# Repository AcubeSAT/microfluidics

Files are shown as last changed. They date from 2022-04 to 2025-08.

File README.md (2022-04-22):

## Description

A repository to host microfluidic chip design schematics and fabrication procedures.
The designs are heavily based on published ones from the [Laboratory of Biological Network Characterization](http://lbnc.epfl.ch/index.html) (LBNC) in EPFL. The LBNC designs can be found [here](http://lbnc.epfl.ch/microfluidic_designs.html). In this repository you will currently find `.dxf` AutoCAD files containing our modified design of the PDMS chip (located in `src/` folder), as well as various figures and `.drawio` files used in [AcubeSAT](https://acubesat.spacedot.gr/)'s [CDR](https://gitlab.com/acubesat/documentation/cdr-public/). You can find a prototype [flow layer](https://benchling.com/protocols/S5hXaszw/flow-layer-pdms-fabrication) and [control layer](https://benchling.com/protocols/ABdPP2IQ/control-layer-pdms-fabrication
) fabrication protocol over at Benchling.

---

<div align="center">
<p>
    <a href="https://benchling.com/organizations/acubesat/">Benchling 🎐🧬</a> &bull;
    <a href="https://gitlab.com/acubesat/documentation/cdr-public/-/blob/master/DDJF/DDJF_PL.pdf?expanded=true&viewer=rich">DDJF_PL 📚🧪</a> &bull;
    <a href="https://spacedot.gr/">SpaceDot 🌌🪐</a> &bull;
    <a href="https://acubesat.spacedot.gr/">AcubeSAT 🛰️🌎</a>
</p>
</div>

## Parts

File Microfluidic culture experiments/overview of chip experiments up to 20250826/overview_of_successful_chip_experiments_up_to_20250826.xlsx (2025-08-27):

Successful chip experiments sum up
 | date | sporulation sample used | total spotted chambers | spot-prime Δt | %viability (viable chambers/overall chambers) |  |  |  |  | chambers ID-FOV based (that grew) | confluency (%) of chambers presenting growth | sporulation medium suspension Δt (if any) | culture media used | Delta height-pressure between inlet-outlet (Δh between inlet and outlet syringes) | Refilling instances | Thermal control | Temperature plots-logs | imaging configuration used (inverted/non) | Chip in FOV by chamber ID | Bonding type | videos | Chip spot pattern | comments
 |  |  |  |  | overall % viability | R1 | R10 | R1-tr | R10-tr
1 | 202401103 | 20241015 (to be verified) since it could be this (https://benchling.com/acubesat/f/lib_Mjy77Noj-sporulations/etr_CO2dx6O2-sporulation-gb_nm-20241015/edit) | 82 | 30mins (+-10mins) | 57.14 | 40% (14/35) | 55.3% (26/47) | N/A | N/A | R1: 1.1 | 2.1 | 4.1 | 1.2 | 2.2 | 3.2 | 5.2 | 4.4 | 5.1 |5.2 | 5.4 | 5.5| 6.1 | 7.1 |||| R10: 1.8 | 1.9 | 1.12 | 2.11 | 2.8 | 2.12 | 3.9 | 3.8 | 3.11 | 3.12 | 4.8 | 4.9 | 4.11 | 4.12 | 5.8 | 5.9 | 5.12 |6.8 | 6.9 | 6.11 | 6.12 | 7.8 | 7.9 | 7.11 | 7.12 ||| 3.15 | 3.18 | 4.18 | - | N/A | YPD | 5cm | refill-flushin after 25h_45 and 40h_45 with syringe | incubator | N/A | inverted chip using this slide holder. Amazon microscope used (https://gitlab.com/acubesat/su/microfluidics/-/blob/master/microfluidic%20setup%20cads/slide_holder_13mm_height__+1mm__-invetred_priming.SLDPRT) | Rows 1-7 Columns 1-18+ | plasma pen | https://gitlab.com/acubesat/su/microfluidics/-/issues/42#note_2191269109 | https://gitlab.com/acubesat/su/microfluidics/-/issues/42#note_2191269109 | high viability can be disputed since the imaging doesn't allow for detection of cross contamination (It is however noteworthy that all visible cross contaminations were not measured as viable chambers)
2 | 20241230-20250101 | 20241015 (https://benchling.com/acubesat/f/lib_Mjy77Noj-sporulations/etr_CO2dx6O2-sporulation-gb_nm-20241015/edit) | 30 | 15-30mins | 26.6 % | N/A | N/A | 26.6% (8/30) | N/A | 1.1 | 87.21325927 | 12h | YPD+G418 | 3cm, inlet and outlet syringe horizontal (syringe retention used) | no refilling instances: the syringe retention mechanism was used to sustain flow (approximately 360deg of rotation after engagement) | amscope illumination stage (incandescent lamp), 22-25deg C ambient temp. Verified 30degC of incubation with the thermal camera | N/A | Amscope illumination stage and Andonstar microscpoe | Rows 1-8 Columns 1-11 | plasma pen | https://gitlab.com/acubesat/su/microfluidics/-/issues/42#note_2370847060 | https://gitlab.com/acubesat/su/microfluidics/-/blob/master/Microfluidic%20culture%20experiments/NM_20241230-20250101_lab2/NM_20241230-20250101_lab2_spotting_l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 | -
 |  |  |  |  |  |  |  |  |  | 1.2 | 82.60456288
 |  |  |  |  |  |  |  |  |  | 3.1 | 75.69255852
 |  |  |  |  |  |  |  |  |  | 5.1 | 80.44540996
 |  |  |  |  |  |  |  |  |  | 5.8 | 80.30826916
 |  |  |  |  |  |  |  |  |  | 6.1 | 68.57686099
 |  |  |  |  |  |  |  |  |  | 6.2 | 72.55567655
 |  |  |  |  |  |  |  |  |  | 6.5 | 52.5258008
3 | 20250715-0724-0728 | 20241015 (allocates of each strain were converted to 10% trehalose specimens on 202504) (https://benchling.com/acubesat/f/lib_Mjy77Noj-sporulations/etr_CO2dx6O2-sporulation-gb_nm-20241015/edit) | 88 (but 10 in the initial FOV) | 30mins | unknown due to unfortunate FOV (and cross contamination that followed) | - | - | - | - | ? | ? | N/A | YPD+G418 | microscope setup: 40cm, horizontal orientation of syringes. |||. stereoscope setup: 14cm, inlet syringe in vertical orientation, outlet in horizontal (syringe retention used: each refilling means 360deg of rotation after engagement) | 20250717 refilling at about 10:15 ||| 20250718 refilling at about 11:15 ||| 20250722 refilling at 15.18-20 ||| delam on mispotted chamber 20250724 refilling at about 1.20 ||| vid in obs 20250728 refilling at 12:28 vid in phone |||. at about 13:33 change outlet-inlet side due to reservoir. |||. 20250731 15:05 refilling | Geomatec heater connected to 5V in arduino Uno R3. Verified incubation temp at 30deg with aht20 sensor. Tested uniformity and temp to be 33deg C with the thermal camera (while connected to the 5v arduino line). The aht20 sensor was mounted to the heater using scotch tape until 0724 11:27. It was later secured with excess kapton on the heater until the end of the test (inside the stereoscope). Note:The stereoscope and the microscope used were constantly covered with their plastic covers | https://gitlab.com/acubesat/su/microfluidics/-/blob/master/Microfluidic%20culture%20experiments/20250715-0724-0728/Temperature_logs-plot_20250715-0731.html | Zeis Axioscop 40 until 0721 14:00 ||| Leica stereoscope with ximea camera inside an eyepiece until 0724 12:30. |||.after 0724 12:38 Leicas native camera was used (required w7 computer) | Rows 1-2 Columns 22-26 | plasma pen | The timelapse video is linked here, it includes all frames in a 15fps video with displayed timestamp and time elapsed from priming. In this displayed elapsed time 21 minutes should be added since priming occured at 0715 14:16 (https://cloud.spacedot.gr/index.php/apps/files/files/594743?openfile=true) | https://gitlab.com/acubesat/su/microfluidics/-/blob/master/Microfluidic%20culture%20experiments/20250715-0724-0728/NM_20250715_CERTH__spotting___logs_-_Sheet1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 | -
4 | 20250723-0801 | 20241015 (allocates of each strain were converted to 10% trehalose specimens on 202504) (https://benchling.com/acubesat/f/lib_Mjy77Noj-sporulations/etr_CO2dx6O2-sporulation-gb_nm-20241015/edit) | 130 (but 59 in FOV) | 30mins | 10.16% | N/A | N/A | 11.36% (5/44) | 6.66% (1/15) | 2,6 (R1-tr) | 8.62700393 | N/A | YPD+G418 | 7cm, inlet syringe in vertical orientation, outlet in horizontal | pump: 0723 4:05, settings: p50-s3-at3mins_p3-s3. |||. 0729 00:00 ||| 0730 7:30 syringe refill ||| 0730 11:50 syringe refill | Incubator. worked until 0728 approximately 20:00. Sensor readings available are ambient temperature. Due to a logging issue in a script most temps were not logged (an arduino nano-esp32 was used instead of the previously tested UNO. After necessary compatibility changes on the .ino script and the python logger-script the sensor appeared to be saving the values but the output csv files were in fact empty, smth which I later realised). Scrolling through the data on the terminal no ambient temp of more than 34deg C was observed. 0728 18:53 incubator temp was observed to be 17.1deg C and the aht20 sensor listed an ambient temp of 33.8deg C | ambient: https://gitlab.com/acubesat/su/microfluidics/-/blob/master/Microfluidic%20culture%20experiments/NM_20250723-0801_lab2/Temp%20&%20RH%20plots-data/aht20_timelin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 | The andonstar microscope was used with the chip inverted inside the slide holder. A custom illumination setup was used including a LED strip attached into the internal walls of the holder. (the andonstar rack and lighting wouldn't fit inside the incubator). To fit the andonstar inside the incubator the andonstar camera-lense was mounted onto the rack of the cainda-amazon- microscope in an intricate and "fragile" setup (not easy to setup and change FOV) (https://gitlab.com/acubesat/su/microfluidics/-/blob/master/microfluidic%20setup%20cads/slide_holder_13mm_height__+1mm__-invetred_priming.SLDPRT) | Rows 1-5 Columns 1-22 | microwave plasma treatement: Initial plasma treatment was unsuccessful (no plasma sparked near the chip) during which the chip was exposed to microwaves for 7seconds (video log available). The vacuum jar was reevacuated and placed again inside the microwave oven for 6 seconds. This time plasma sparked on the chip and slide. Bonding was subsequently immediate and strong | The timelapse video is linked here, it includes all frames in a 15fps video with displayed timestamp and time elapsed from priming. Priming of the chip occured at 07:23 1:48 so real elapsed time should be calculated based on this (there seems to be a problem in the initially shown elapsed time). Regarding the elapsed time shown after 0723 20:00 19h 28minutes and 50seconds need to be added to reflect the correct elapsed time (https://cloud.spacedot.gr/index.php/apps/files/files/594858?openfile=true) | https://gitlab.com/acubesat/su/microfluidics/-/blob/master/Microfluidic%20culture%20experiments/NM_20250723-0801_lab2/NM_20250723_lab2_spotting_layout__logs__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 | This is the first successful microfluidic culture with microwave plasma bonded chip! This validates the method for future testing. The spores endured 13s exposure to microwaves which is impressive (it is quite likely the reason for the significant decrease in viability)
 |  |  |  |  |  |  |  |  |  | 2,7 (R1-tr) | 100.7921616
 |  |  |  |  |  |  |  |  |  | 2,15 (R1-tr) | 29.61937955
 |  |  |  |  |  |  |  |  |  | 1,8 (R1-tr) | 8.483221005
 |  |  |  |  |  |  |  |  |  | 1,15 (R1-tr) | 50.97121498
 |  |  |  |  |  |  |  |  |  | 3.22 (R10-tr) | 35.9865942

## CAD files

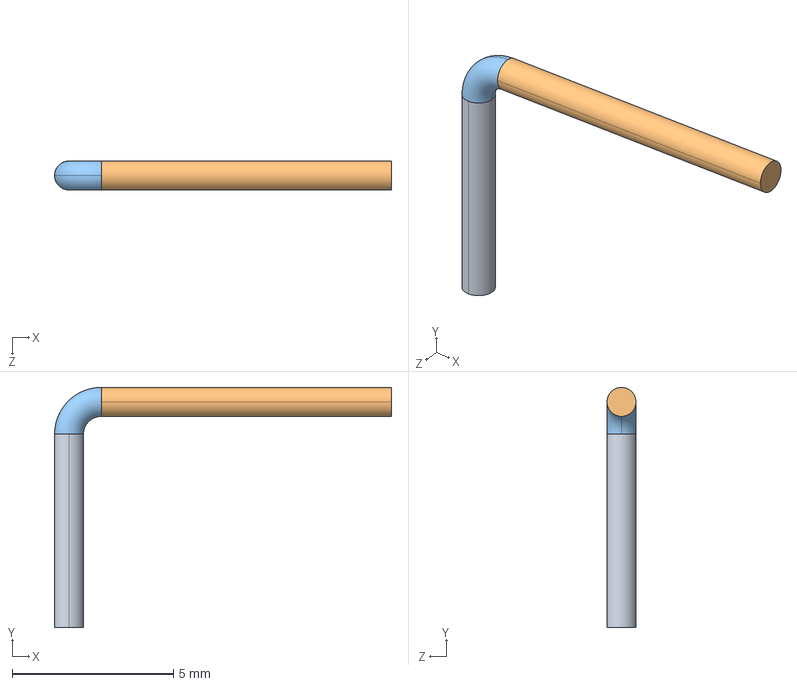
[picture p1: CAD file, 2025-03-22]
microfluidic setup cads/Pin cads/0.9mm 20G solid pin/corrected_0.9mmOD_20G_solid_pin.STEP
10.5 x 7.45 x 0.9 mm

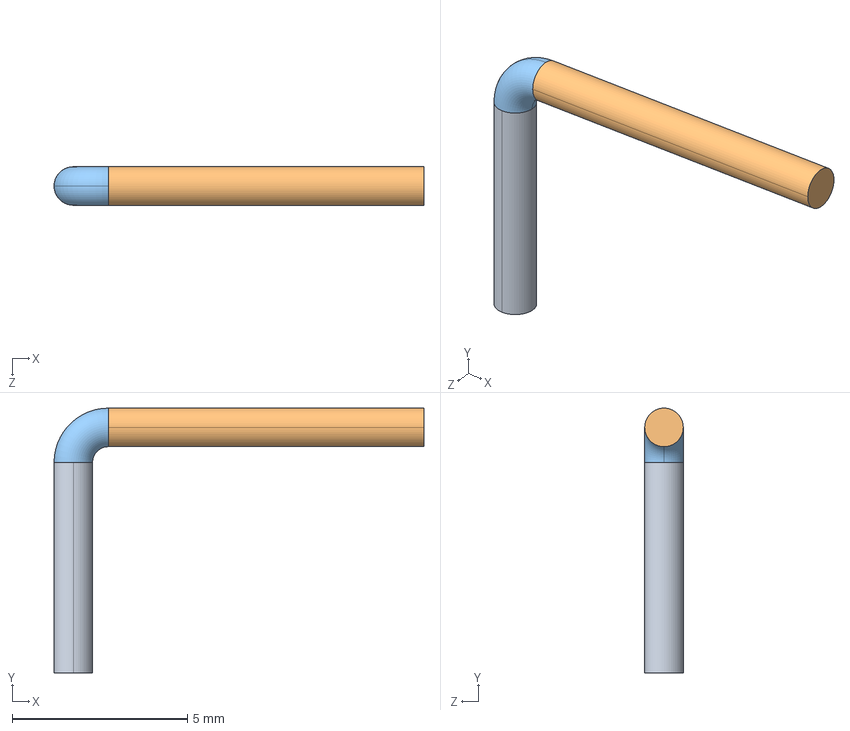
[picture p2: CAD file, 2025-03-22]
microfluidic setup cads/Pin cads/1.1mm solid pin/1.1_mmOD_solid_pin.STEP
10.6 x 7.55 x 1.10 mm

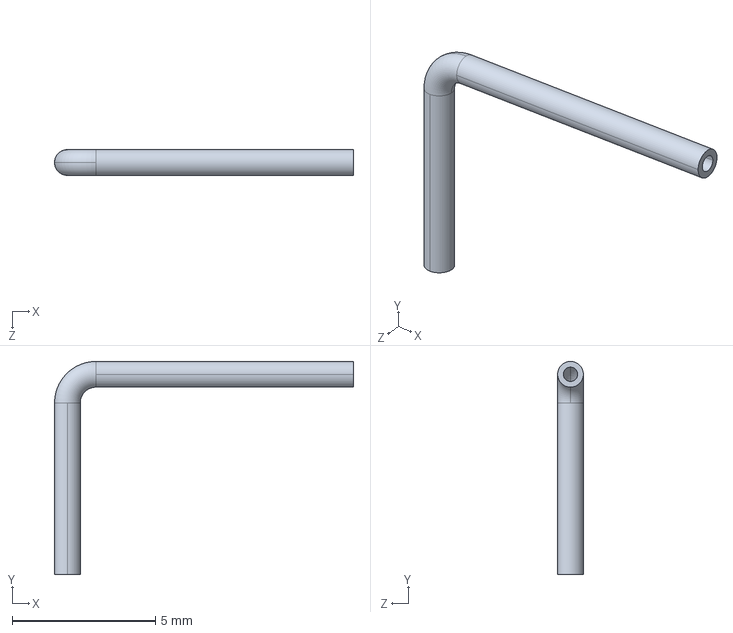
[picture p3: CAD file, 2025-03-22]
microfluidic setup cads/Pin cads/20G hollow pins -0.9mmOD 0.5mmID/20G_pins_-hollow-_0.5mmID_and_0.9mm_OD.STEP
10.5 x 7.45 x 0.9 mm

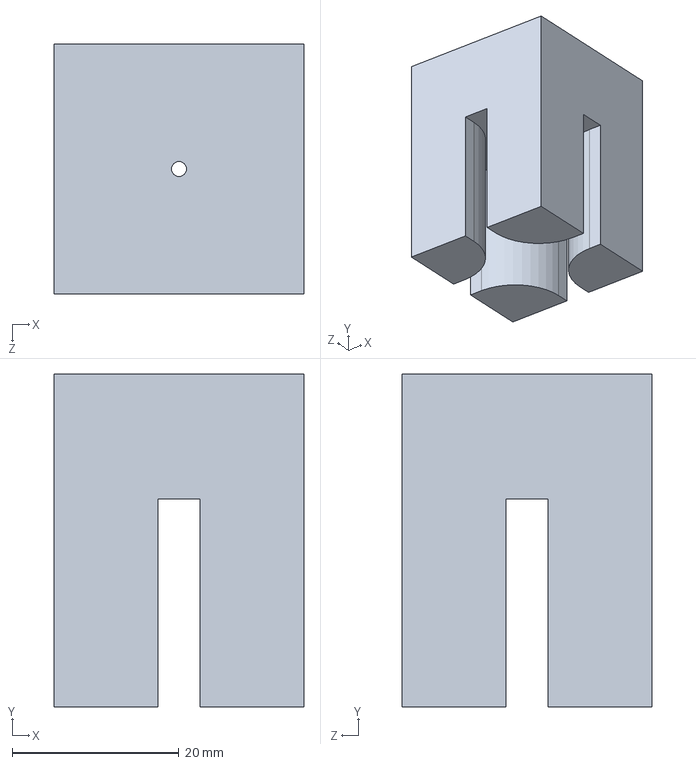
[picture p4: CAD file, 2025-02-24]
microfluidic setup cads/pin_holder_sonicator.SLDPRT
30.0 x 40.0 x 30.0 mm

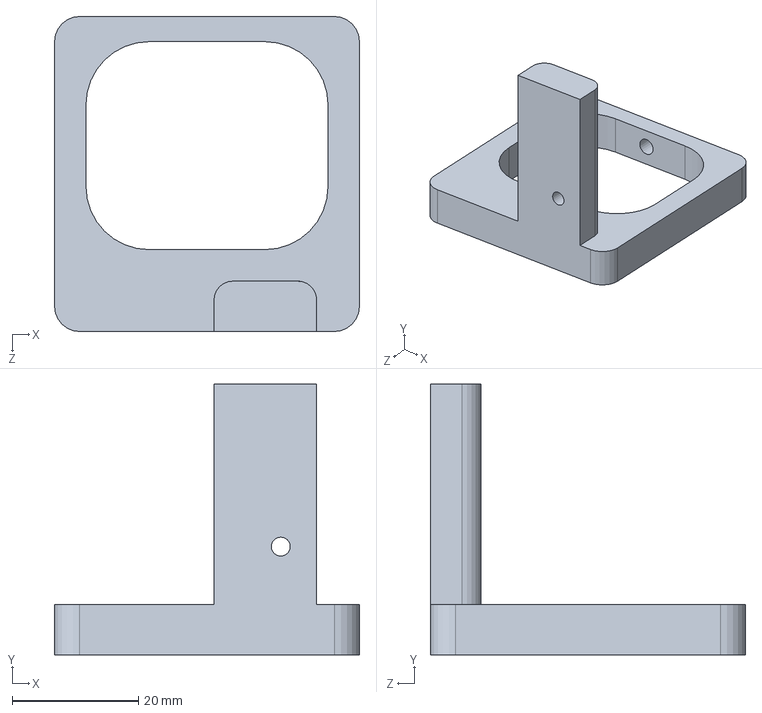
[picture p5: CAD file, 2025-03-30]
microfluidic setup cads/Spotter-bonding-cads/spotter-bond-V4/pen_holder_part_v2.SLDPRT
48.4 x 43.0 x 50.0 mm

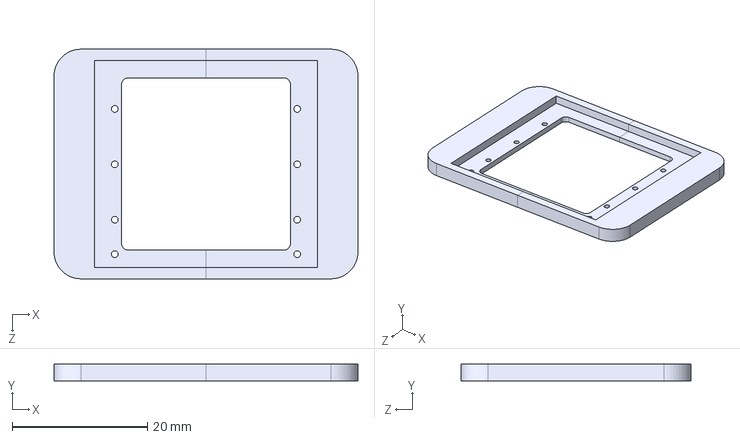
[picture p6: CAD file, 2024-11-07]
microfluidic setup cads/Spacer-Sheet_cad_1mm_-cut.STEP
45.0 x 2.50 x 34.0 mm

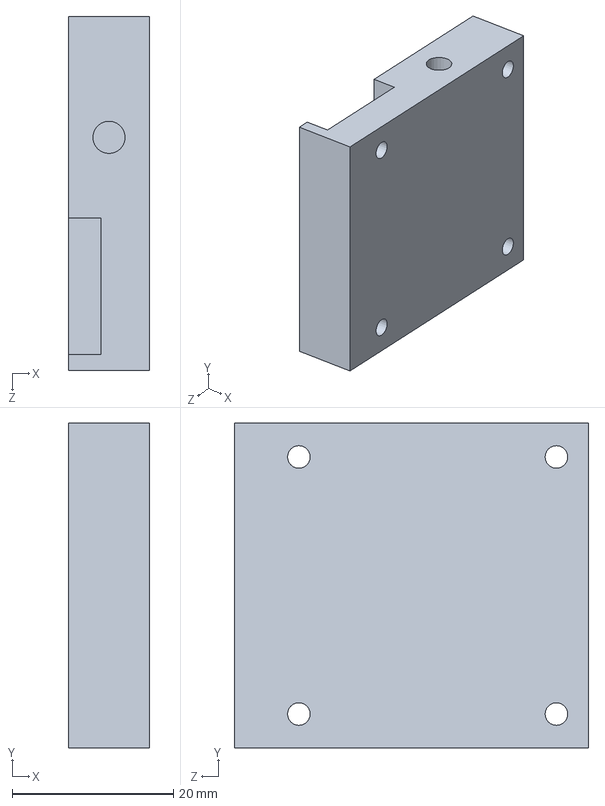
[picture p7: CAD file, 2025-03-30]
microfluidic setup cads/Spotter-bonding-cads/spotter-bond-V4/pin_holder_2_for_pen_upside.SLDPRT
10.0 x 40.3 x 43.9 mm

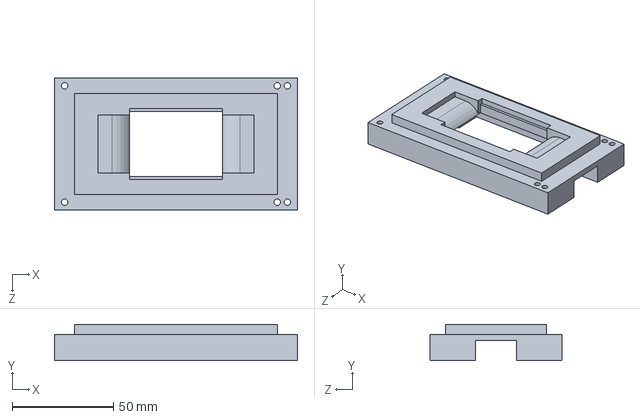
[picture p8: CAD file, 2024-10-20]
microfluidic setup cads/slide_holder_13mm_height__+1mm__-invetred_priming.SLDPRT
120.0 x 18.0 x 65.0 mm

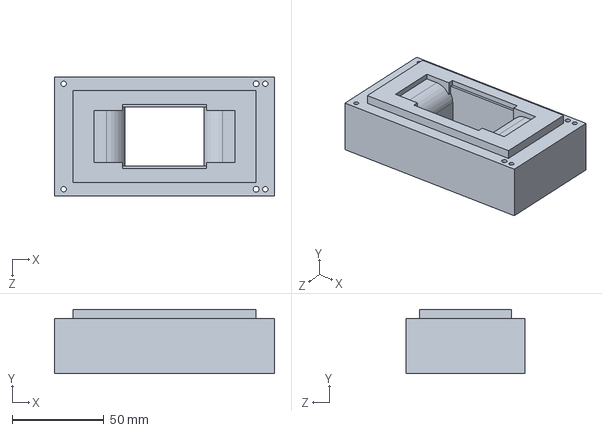
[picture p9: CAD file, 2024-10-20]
microfluidic setup cads/slide_holder__v1_-31mm_height.SLDPRT
120.0 x 35.0 x 65.0 mm

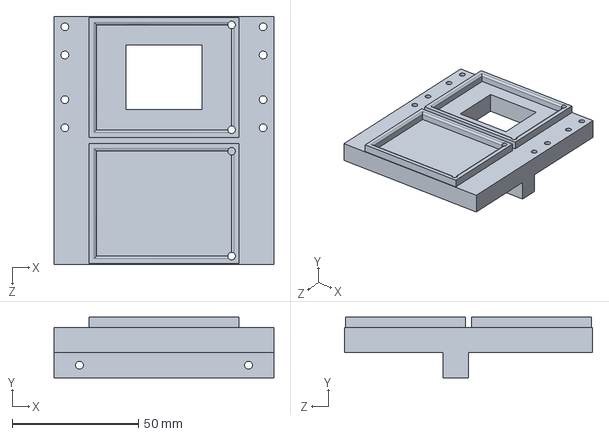
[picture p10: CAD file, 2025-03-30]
microfluidic setup cads/Spotter-bonding-cads/spotter-bond-V4/double_holder_slot__for_top_and_bottom_v4.SLDPRT
86.9 x 24.0 x 98.2 mm

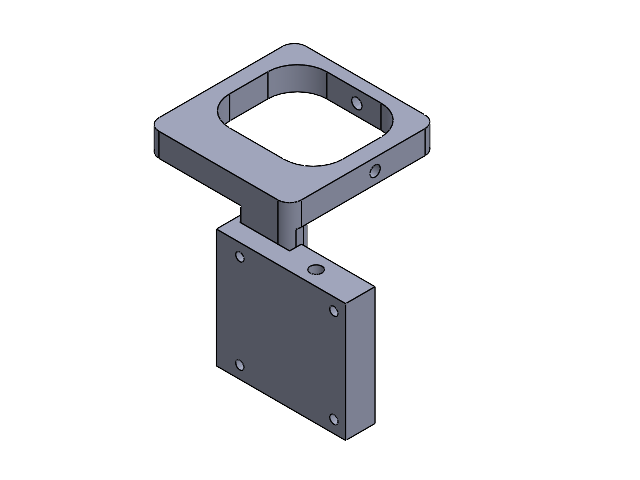
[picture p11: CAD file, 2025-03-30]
microfluidic setup cads/Spotter-bonding-cads/spotter-bond-V4/assembly_v2_pen_holder.SLDASM
pin holder 2 for pen upside
Part2^chip hold align pin insert

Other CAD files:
src/baseline/MITOMI_spacedot_complete.dxf
src/designs/Biodisplay_spacedot_CDR_complete.dxf
original/biodisplay.dxf
src/designs/MITOMI_incr_dist_spacedot.dxf
src/baseline/MITOMI_spacedot.dxf
src/designs/Biodisplay_spacedot.dxf
src/designs/Biodisplay_spacedot_CDR_sub.dxf
microfluidic setup cads/Pin cads/0.9mm 20G solid pin/corrected_0.9mmOD_20G_solid_pin.SLDPRT
microfluidic setup cads/Pin cads/0.9mm 20G solid pin/corrected_0.9mmOD_20G_solid_pin.STL
microfluidic setup cads/Pin cads/1.1mm solid pin/1.1_mmOD_solid_pin.SLDPRT
microfluidic setup cads/Pin cads/1.1mm solid pin/1.1_mmOD_solid_pin.STL
microfluidic setup cads/Pin cads/20G hollow pins -0.9mmOD 0.5mmID/20G_pins_-hollow-_0.5mmID_and_0.9mm_OD.SLDPRT
microfluidic setup cads/Pin cads/20G hollow pins -0.9mmOD 0.5mmID/20G_pins_-hollow-_0.5mmID_and_0.9mm_OD.STL
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

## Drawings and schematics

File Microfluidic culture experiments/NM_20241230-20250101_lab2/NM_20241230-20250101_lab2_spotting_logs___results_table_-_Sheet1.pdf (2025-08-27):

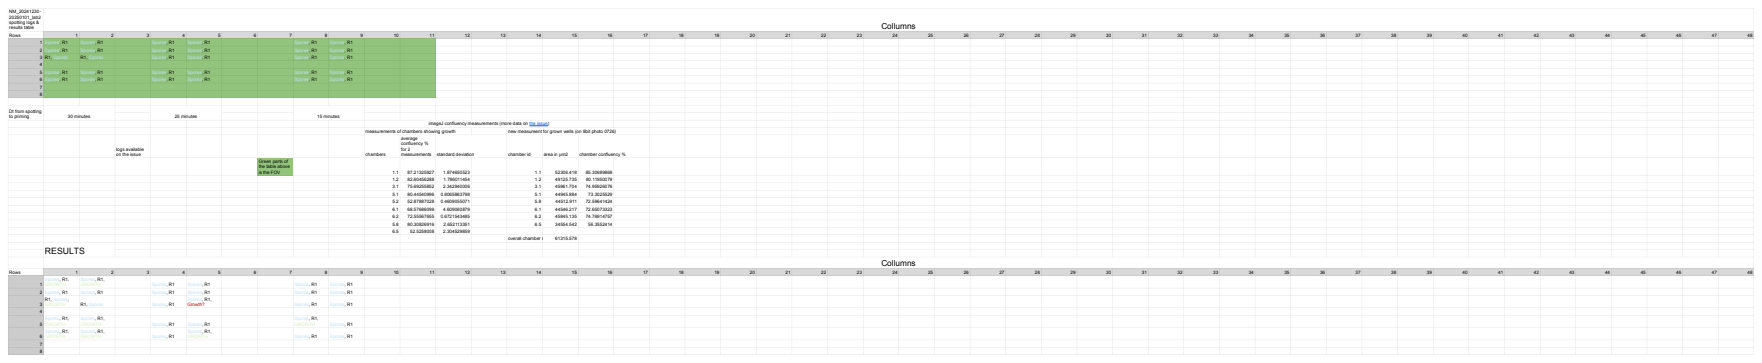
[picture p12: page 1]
NM_20241230- 20250101_lab2 spotting logs & results table; Collumns; Rows; Spores, R1; Spores, R1 2; Spores, R1 3; R1, Spores; Spores, R1 45; Spores, R1 6; Spores, R1 78 Dt from spotting; to priming; 30 minutes; 25 minutes; 15 minutes; imageJ confluency measurements (more data on the issue) measurements of chambers showing growth; new measureent for grown wells (on 8bit photo 0726); logs available on the issue; chambers; average confluency %; for 2 measurements; standard deviation; chamber id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

Green parts of
the table above

Rows | Spores, R1, GROWTH 1 2 3 4 5 6 7 8 9 10 11 12 13 14 15 16 17 18 19 20 21 22 23 24 25 26 27 28 29 30 31 32 33 34 35 36 37 38 39 40 41 42 43 44 45 46 47 48 1

Spores, R1 R1, Spores, GROWTH Spores, R1, GROWTH Spores, R1, GROWTH Spores, R1 R1, Spores Spores, R1 Spores, R1 Spores, R1 Spores, R1 Spores, R1 Spores, R1, Growth? Spores, R1 Spores, R1 Spores, R1 Spores, R1 2 Spores, R1 3 Spores, R1 45 Spores, R1, GROWTH Spores, R1, GROWTH Spores, R1 Spores, R1 Spores, R1, GROWTH Spores, R1 6 Spores, R1, GROWTH Spores, R1 Spores, R1, GROWTH Spores, R1 Spores, R1 78

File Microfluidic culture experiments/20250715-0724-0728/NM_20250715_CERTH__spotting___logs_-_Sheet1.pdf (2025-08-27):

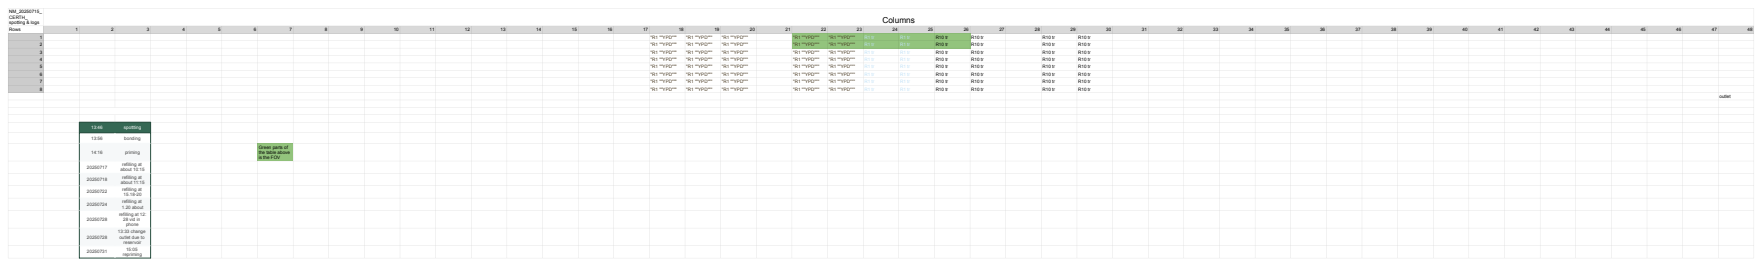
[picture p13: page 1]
NM_20250715_ CERTH_ spotting & logs; Columns; Rows; "R1 ""YPD"""; outlet; priming; Green parts of

13:46 | spottting

13:56 | bonding

20250717 | refilling at about 10:15

the table above
is the FOV

20250718 | refilling at about 11:15

20250722 | refilling at 15.18-20

20250724 | refilling at 1.20 about 20250728

refilling at 12: 28 vid in phone

20250728 | 13:33 change outlet due to reservoir 20250731 15:05 repriming

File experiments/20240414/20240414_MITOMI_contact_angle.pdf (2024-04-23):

Left | Middle | Right

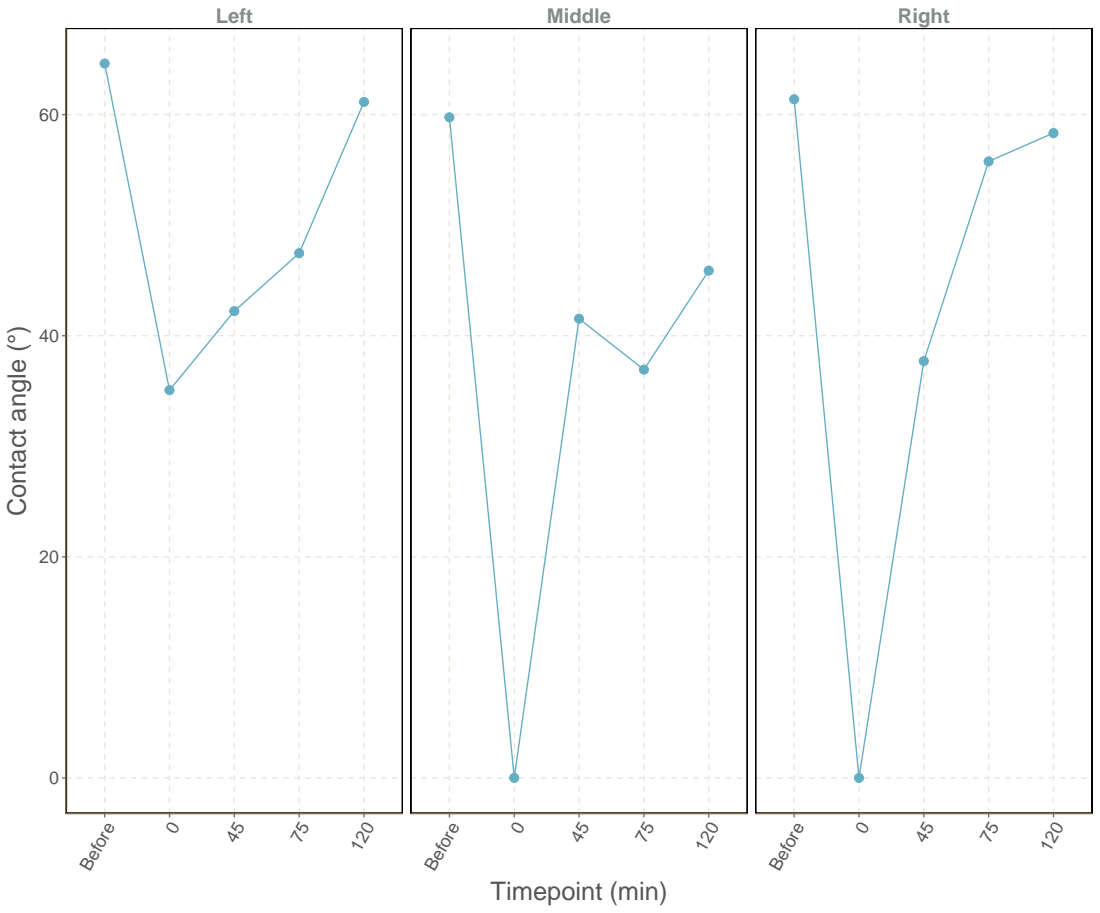
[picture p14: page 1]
Before; Timepoint (min); Contact angle (°)

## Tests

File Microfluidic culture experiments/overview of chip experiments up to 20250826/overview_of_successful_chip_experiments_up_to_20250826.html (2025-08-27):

| A | B | C | D | E | F | G | H | I | J | K | L | M | N | O | P | Q | R | S | T | U | V | W | X | Y | Z | AA
1
2 | | | Successful chip experiments sum up
3 | | | | date | sporulation sample used | total spotted chambers | spot-prime Δt | %viability (viable chambers/overall chambers) | | | | | chambers ID-FOV based (that grew) | confluency (%) of chambers presenting growth | sporulation medium suspension Δt (if any) | culture media used | Delta height-pressure between inlet-outlet (Δh between inlet and outlet syringes) | Refilling instances | Thermal control | Temperature plots-logs | imaging configuration used (inverted/non) | Chip in FOV by chamber ID | Bonding type | videos | Chip spot pattern | comments
4 | | | | | | | | overall % viability | R1 | R10 | R1-tr | R10-tr
5 | | | 1 | 202401103 | 20241015 (to be verified) (https://benchling.com/acubesat/f/lib_Mjy77Noj-sporulations/etr_CO2dx6O2-sporulation-gb_nm-20241015/edit) since it could be this (https://benchling.com/acubesat/f/lib_Mjy77Noj-sporulations/etr_Rs7Qbz9h-sporulation-nm-20240920/edit) | 82 | 30mins (+-10mins) | 57.14 | 40% (14/35) | 55.3% (26/47) | N/A | N/A | R1: 1.1 | 2.1 | 4.1 | 1.2 | 2.2 | 3.2 | 5.2 | 4.4 | 5.1 |5.2 | 5.4 | 5.5| 6.1 | 7.1 |||| R10: 1.8 | 1.9 | 1.12 | 2.11 | 2.8 | 2.12 | 3.9 | 3.8 | 3.11 | 3.12 | 4.8 | 4.9 | 4.11 | 4.12 | 5.8 | 5.9 | 5.12 |6.8 | 6.9 | 6.11 | 6.12 | 7.8 | 7.9 | 7.11 | 7.12 ||| 3.15 | 3.18 | 4.18 | - | N/A | YPD | 5cm | refill-flushin after 25h_45 and 40h_45 with syringe | incubator | N/A | inverted chip using this (https://gitlab.com/acubesat/su/microfluidics/-/blob/master/microfluidic%20setup%20cads/slide_holder_13mm_height__+1mm__-invetred_priming.SLDPRT) slide holder. Amazon microscope used | Rows 1-7 Columns 1-18+ | plasma pen | https://gitlab.com/acubesat/su/microfluidics/-/issues/42#note_2191269109 | https://gitlab.com/acubesat/su/microfluidics/-/issues/42#note_2191269109 | high viability can be disputed since the imaging doesn't allow for detection of cross contamination (It is however noteworthy that all visible cross contaminations were not measured as viable chambers)
6 | | | 2 | 20241230-20250101 | 20241015 (https://benchling.com/acubesat/f/lib_Mjy77Noj-sporulations/etr_CO2dx6O2-sporulation-gb_nm-20241015/edit) | 30 | 15-30mins | 26.6 % | N/A | N/A | 26.6% (8/30) | N/A | 1.1 | 87.21325927 | 12h | YPD+G418 | 3cm, inlet and outlet syringe horizontal (syringe retention used) | no refilling instances: the syringe retention mechanism was used to sustain flow (approximately 360deg of rotation after engagement) | amscope illumination stage (incandescent lamp), 22-25deg C ambient temp. Verified 30degC of incubation with the thermal camera | N/A | Amscope illumination stage and Andonstar microscpoe | Rows 1-8 Columns 1-11 | plasma pen | https://gitlab.com/acubesat/su/microfluidics/-/issues/42#note_2370847060 | https://gitlab.com/acubesat/su/microfluidics/-/blob/master/Microfluidic%20culture%20experiments/NM_20241230-20250101_lab2/NM_20241230-20250101_lab2_spotting_logs___r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 | -
7 | | | | | | | | | | | | | 1.2 | 82.60456288
8 | | | | | | | | | | | | | 3.1 | 75.69255852
9 | | | | | | | | | | | | | 5.1 | 80.44540996
10 | | | | | | | | | | | | | 5.8 | 80.30826916
11 | | | | | | | | | | | | | 6.1 | 68.57686099
12 | | | | | | | | | | | | | 6.2 | 72.55567655
13 | | | | | | | | | | | | | 6.5 | 52.5258008
14 | | | 3 | 20250715-0724-0728 | 20241015 (https://benchling.com/acubesat/f/lib_Mjy77Noj-sporulations/etr_CO2dx6O2-sporulation-gb_nm-20241015/edit) (allocates of each strain were converted to 10% trehalose specimens on 202504) | 88 (but 10 in the initial FOV) | 30mins | unknown due to unfortunate FOV (and cross contamination that followed) | - | - | - | - | ? | ? | N/A | YPD+G418 | microscope setup: 40cm, horizontal orientation of syringes. |||. stereoscope setup: 14cm, inlet syringe in vertical orientation, outlet in horizontal (syringe retention used: each refilling means 360deg of rotation after engagement) | 20250717 refilling at about 10:15 ||| 20250718 refilling at about 11:15 ||| 20250722 refilling at 15.18-20 ||| delam on mispotted chamber 20250724 refilling at about 1.20 ||| vid in obs 20250728 refilling at 12:28 vid in phone |||. at about 13:33 change outlet-inlet side due to reservoir. |||. 20250731 15:05 refilling | Geomatec heater connected to 5V in arduino Uno R3. Verified incubation temp at 30deg with aht20 sensor. Tested uniformity and temp to be 33deg C with the thermal camera (while connected to the 5v arduino line). The aht20 sensor was mounted to the heater using scotch tape until 0724 11:27. It was later secured with excess kapton on the heater until the end of the test (inside the stereoscope). Note:The stereoscope and the microscope used were constantly covered with their plastic covers | https://gitlab.com/acubesat/su/microfluidics/-/blob/master/Microfluidic%20culture%20experiments/20250715-0724-0728/Temperature_logs-plot_20250715-0731.html | Zeis Axioscop 40 until 0721 14:00 ||| Leica stereoscope with ximea camera inside an eyepiece until 0724 12:30. |||.after 0724 12:38 Leicas native camera was used (required w7 computer) | Rows 1-2 Columns 22-26 | plasma pen | The timelapse video is linked here (https://cloud.spacedot.gr/index.php/apps/files/files/594743?openfile=true), it includes all frames in a 15fps video with displayed timestamp and time elapsed from priming. In this displayed elapsed time 21 minutes should be added since priming occured at 0715 14:16 | https://gitlab.com/acubesat/su/microfluidics/-/blob/master/Microfluidic%20culture%20experiments/20250715-0724-0728/NM_20250715_CERTH__spotting___logs_-_Sheet1.pdf | -

15

4

20250723-0801

20241015 (https://benchling.com/acubesat/f/lib_Mjy77Noj-sporulations/etr_CO2dx6O2-sporulation-gb_nm-20241015/edit) (allocates of each strain were converted to 10% trehalose specimens on 202504)

130 (but 59 in FOV)

30mins

10.16%

N/A

N/A

11.36% (5/44)

6.66% (1/15)

2,6 (R1-tr)

8.62700393

N/A

YPD+G418

7cm, inlet syringe in vertical orientation, outlet in horizontal

pump: 0723 4:05, settings: p50-s3-at3mins_p3-s3. |||. 0729 00:00 ||| 0730 7:30 syringe refill ||| 0730 11:50 syringe refill

Incubator. worked until 0728 approximately 20:00. Sensor readings available are ambient temperature. Due to a logging issue in a script most temps were not logged (an arduino nano-esp32 was used instead of the previously tested UNO. After necessary compatibility changes on the .ino script and the python logger-script the sensor appeared to be saving the values but the output csv files were in fact empty, smth which I later realised). Scrolling through the data on the terminal no ambient temp of more than 34deg C was observed. 0728 18:53 incubator temp was observed to be 17.1deg C and the aht20 sensor listed an ambient temp of 33.8deg C

ambient: https://gitlab.com/acubesat/su/microfluidics/-/blob/master/Microfluidic%20culture%20experiments/NM_20250723-0801_lab2/Temp%20&%20RH%20plots-data/aht20_timeline_20250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

The andonstar microscope was used with the chip inverted inside the slide holder (https://gitlab.com/acubesat/su/microfluidics/-/blob/master/microfluidic%20setup%20cads/slide_holder_13mm_height__+1mm__-invetred_priming.SLDPRT). A custom illumination setup was used including a LED strip attached into the internal walls of the holder. (the andonstar rack and lighting wouldn't fit inside the incubator). To fit the andonstar inside the incubator the andonstar camera-lense was mounted onto the rack of the cainda-amazon- microscope (https://www.amazon.de/dp/B081L4Y98G?psc=1&ref_=cm_sw_r_cp_ud_ct_2FXTQT1BFDR92B6G9DYQ_1) in an intricate and "fragile" setup (not easy to setup and change FOV)

Rows 1-5 Columns 1-22

microwave plasma treatement: Initial plasma treatment was unsuccessful (no plasma sparked near the chip) during which the chip was exposed to microwaves for 7seconds (video log available). The vacuum jar was reevacuated and placed again inside the microwave oven for 6 seconds. This time plasma sparked on the chip and slide. Bonding was subsequently immediate and strong

The timelapse video is linked here (https://cloud.spacedot.gr/index.php/apps/files/files/594858?openfile=true), it includes all frames in a 15fps video with displayed timestamp and time elapsed from priming. Priming of the chip occured at 07:23 1:48 so real elapsed time should be calculated based on this (there seems to be a problem in the initially shown elapsed time). Regarding the elapsed time shown after 0723 20:00 19h 28minutes and 50seconds need to be added to reflect the correct elapsed time

https://gitlab.com/acubesat/su/microfluidics/-/blob/master/Microfluidic%20culture%20experiments/NM_20250723-0801_lab2/NM_20250723_lab2_spotting_layout__logs___result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

This is the first successful microfluidic culture with microwave plasma bonded chip! This validates the method for future testing. The spores endured 13s exposure to microwaves which is impressive (it is quite likely the reason for the significant decrease in viability)
16 | | | | | | | | | | | | | 2,7 (R1-tr) | 100.7921616
17 | | | | | | | | | | | | | 2,15 (R1-tr) | 29.61937955
18 | | | | | | | | | | | | | 1,8 (R1-tr) | 8.483221005
19 | | | | | | | | | | | | | 1,15 (R1-tr) | 50.97121498
20 | | | | | | | | | | | | | 3.22 (R10-tr) | 35.9865942

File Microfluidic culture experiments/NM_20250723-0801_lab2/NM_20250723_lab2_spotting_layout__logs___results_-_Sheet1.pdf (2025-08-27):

NM_20250723_
lab2_spotting
layout & logs | Collumns
Rows | 1 | 2 | 3 | 4 | 5 | 6 | 7 | 8 | 9 | 10 | 11 | 12 | 13 | 14 | 15 | 16 | 17 | 18 | 19 | 20 | 21 | 22 | 23 | 24 | 25 | 26 | 27 | 28 | 29 | 30 | 31 | 32 | 33 | 34 | 35 | 36 | 37 | 38 | 39 | 40 | 41 | 42 | 43 | 44 | 45 | 46 | 47 | 48 1 R1 tr | R1 tr | R1 tr | R1 tr | R1 tr | R1 tr | R1 tr | R1 tr | R1 tr | R10 tr | R10 tr | R10 tr | R10 tr | R10 tr | R10 tr | R10 tr | R10 tr 2 R1 tr | R1 tr | R1 tr | R1 tr | R1 tr | R1 tr | R1 tr | R1 tr | R1 tr | R10 tr | R10 tr | R10 tr | R10 tr | R10 tr | R10 tr | R10 tr | R10 tr 3 R1 tr | R1 tr | R1 tr | R1 tr | R1 tr | R1 tr | R1 tr | R1 tr | R10 tr | R10 tr | R10 tr | R10 tr | R10 tr | R10 tr | R10 tr | R10 tr 4 R1 tr | R1 tr | R1 tr | R1 tr | R1 tr | R1 tr | R1 tr | R1 tr | R10 tr | R10 tr | R10 tr | R10 tr | R10 tr | R10 tr | R10 tr | R10 tr 5 R1 tr | R1 tr | R1 tr | R1 tr | R1 tr | R1 tr | R1 tr | R1 tr | R10 tr | R10 tr | R10 tr | R10 tr | R10 tr | R10 tr | R10 tr | R10 tr 6 R1 tr | R1 tr | R1 tr | R1 tr | R1 tr | R1 tr | R1 tr | R1 tr | R10 tr | R10 tr | R10 tr | R10 tr | R10 tr | R10 tr | R10 tr | R10 tr 7 R1 tr | R1 tr | R1 tr | R1 tr | R1 tr | R1 tr | R1 tr | R1 tr | R10 tr | R10 tr | R10 tr | R10 tr | R10 tr | R10 tr | R10 tr | R10 tr 8 R1 tr | R1 tr | R1 tr | R1 tr | R1 tr | R1 tr | R1 tr | R1 tr | R10 tr | R10 tr | R10 tr | R10 tr | R10 tr | R10 tr | R10 tr | R10 tr
FOV BASED CHAMBER ID | Green parts of the table above is the FOV
Column 1 | Column 2 | Column 3 | Column 1 | Column 2
1.32 | end
1:39 | bonding
1:48 | priming
until 3:42 | storage in RT
3.42 | tube prefilling with YPD+G | ran the pump for 25s at p3 s3
3.45 | syringe 5.1mL 4:05 | p50-s3-at3mins_p3-s3 | for 1minute | (also logged in video time 2:40-3:37) 20250725 | remote failed priming attempts_due to hardware_remote_failure(details in 20250728 | 20:00 | repriming very difficult-not possible from inlet 729 | at about 00:00 | tried repriming with syringe from the outlet to unclog (ended with the initial inlet-outlet config) 730
| at about 7:00 repriming | vid avail on pdms laptop

20250730

at 11:50 repriming with syringe | video on pdms2laptop, RESULTS R1-TR VIABLE CHAMBERS | R10-TR VIABLE CHAMBERS

VIABILITY

5/44 | 1/15
11.36% | 7%
chamber ID | area (μm2) | confluency % 1 2,6 | 5158.517 | 8.62700393 2 2,7 | 60268.673 | 100.7921616 3 2,15 | 17710.908 | 29.61937955 4 1,8 | 5072.542 | 8.483221005 5 1,15 | 30478.238 | 50.97121498 6 | 3.22 | 21518.184 | 35.9865942 overall chamber measured | 59795

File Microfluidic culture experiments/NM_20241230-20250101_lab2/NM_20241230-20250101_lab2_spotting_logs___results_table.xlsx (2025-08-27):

NM_20241230-20250101_lab2 spotting logs & results table | Collumns
Rows | 1 | 2 | 3 | 4 | 5 | 6 | 7 | 8 | 9 | 10 | 11 | 12 | 13 | 14 | 15 | 16 | 17 | 18 | 19 | 20 | 21 | 22 | 23 | 24 | 25 | 26 | 27 | 28 | 29 | 30 | 31 | 32 | 33 | 34 | 35 | 36 | 37 | 38 | 39 | 40 | 41 | 42 | 43 | 44 | 45 | 46 | 47 | 48
1 | Spores, R1 | Spores, R1 |  | Spores, R1 | Spores, R1 |  |  | Spores, R1 | Spores, R1
2 | Spores, R1 | Spores, R1 |  | Spores, R1 | Spores, R1 |  |  | Spores, R1 | Spores, R1
3 | R1, Spores | R1, Spores |  | Spores, R1 | Spores, R1 |  |  | Spores, R1 | Spores, R1
4
5 | Spores, R1 | Spores, R1 |  | Spores, R1 | Spores, R1 |  |  | Spores, R1 | Spores, R1
6 | Spores, R1 | Spores, R1 |  | Spores, R1 | Spores, R1 |  |  | Spores, R1 | Spores, R1
7
8
Dt from spotting to priming | 30 minutes |  |  | 25 minutes |  |  |  | 15 minutes
 |  |  |  |  |  |  |  |  |  | imageJ confluency measurements (more data on the issue) (https://gitlab.com/acubesat/su/microfluidics/-/issues/42)
 |  |  |  |  |  |  |  |  |  | measurements of chambers showing growth |  |  |  | new measureent for grown wells (on 8bit photo 0726)
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

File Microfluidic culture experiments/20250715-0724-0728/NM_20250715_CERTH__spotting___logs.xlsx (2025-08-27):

NM_20250715_CERTH_ spotting & logs | Columns
Rows | 1 | 2 | 3 | 4 | 5 | 6 | 7 | 8 | 9 | 10 | 11 | 12 | 13 | 14 | 15 | 16 | 17 | 18 | 19 | 20 | 21 | 22 | 23 | 24 | 25 | 26 | 27 | 28 | 29 | 30 | 31 | 32 | 33 | 34 | 35 | 36 | 37 | 38 | 39 | 40 | 41 | 42 | 43 | 44 | 45 | 46 | 47 | 48
1 |  |  |  |  |  |  |  |  |  |  |  |  |  |  |  |  |  | "R1 ""YPD""" | "R1 ""YPD""" | "R1 ""YPD""" |  | "R1 ""YPD""" | "R1 ""YPD""" | R1 tr | R1 tr | R10 tr | R10 tr |  | R10 tr | R10 tr
2 |  |  |  |  |  |  |  |  |  |  |  |  |  |  |  |  |  | "R1 ""YPD""" | "R1 ""YPD""" | "R1 ""YPD""" |  | "R1 ""YPD""" | "R1 ""YPD""" | R1 tr | R1 tr | R10 tr | R10 tr |  | R10 tr | R10 tr
3 |  |  |  |  |  |  |  |  |  |  |  |  |  |  |  |  |  | "R1 ""YPD""" | "R1 ""YPD""" | "R1 ""YPD""" |  | "R1 ""YPD""" | "R1 ""YPD""" | R1 tr | R1 tr | R10 tr | R10 tr |  | R10 tr | R10 tr
4 |  |  |  |  |  |  |  |  |  |  |  |  |  |  |  |  |  | "R1 ""YPD""" | "R1 ""YPD""" | "R1 ""YPD""" |  | "R1 ""YPD""" | "R1 ""YPD""" | R1 tr | R1 tr | R10 tr | R10 tr |  | R10 tr | R10 tr
5 |  |  |  |  |  |  |  |  |  |  |  |  |  |  |  |  |  | "R1 ""YPD""" | "R1 ""YPD""" | "R1 ""YPD""" |  | "R1 ""YPD""" | "R1 ""YPD""" | R1 tr | R1 tr | R10 tr | R10 tr |  | R10 tr | R10 tr
6 |  |  |  |  |  |  |  |  |  |  |  |  |  |  |  |  |  | "R1 ""YPD""" | "R1 ""YPD""" | "R1 ""YPD""" |  | "R1 ""YPD""" | "R1 ""YPD""" | R1 tr | R1 tr | R10 tr | R10 tr |  | R10 tr | R10 tr
7 |  |  |  |  |  |  |  |  |  |  |  |  |  |  |  |  |  | "R1 ""YPD""" | "R1 ""YPD""" | "R1 ""YPD""" |  | "R1 ""YPD""" | "R1 ""YPD""" | R1 tr | R1 tr | R10 tr | R10 tr |  | R10 tr | R10 tr
8 |  |  |  |  |  |  |  |  |  |  |  |  |  |  |  |  |  | "R1 ""YPD""" | "R1 ""YPD""" | "R1 ""YPD""" |  | "R1 ""YPD""" | "R1 ""YPD""" | R1 tr | R1 tr | R10 tr | R10 tr |  | R10 tr | R10 tr
 |  |  |  |  |  |  |  |  |  |  |  |  |  |  |  |  |  |  |  |  |  |  |  |  |  |  |  |  |  |  |  |  |  |  |  |  |  |  |  |  |  |  |  |  |  |  |  | outlet
 |  | 13:46 | spottting
 |  | 13:56:00 | bonding
 |  | 14:16:00 | priming |  |  |  | Green parts of the table above is the FOV
 |  | 20250717 | refilling at about 10:15
 |  | 20250718 | refilling at about 11:15
 |  | 20250722 | refilling at 15.18-20
 |  | 20250724 | refilling at 1.20 about
 |  | 20250728 | refilling at 12:28 vid in phone
 |  | 20250728 | 13:33 change outlet due to reservoir
 |  | 20250731 | 15:05 repriming

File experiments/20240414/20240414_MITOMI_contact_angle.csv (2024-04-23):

Minutes | Section | Angle
Before | Left | 64.622
Before | Middle | 59.752
Before | Right | 61.39
0 | Left | 35.076
0 | Middle | 0
0 | Right | 0
45 | Left | 42.226
45 | Middle | 41.54
45 | Right | 37.704
75 | Left | 47.467
75 | Middle | 36.934
75 | Right | 55.768
120 | Left | 61.148
120 | Middle | 45.885
120 | Right | 58.333

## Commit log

2020-07-11 Add single sub-experiment layout
    [biodisplay_sub.dwg, biodisplay_sub.dxf]
2020-07-11 Add original LBNC layout design
    From "A microfluidic display", Volpetti, Petrova, Maerkl
    [biodisplay.dxf, biodisplay_sub.dwg, biodisplay_sub.dxf]
2020-07-11 Add test line for the flow layer
    [biodisplay_sub_test_flow.dwg, biodisplay_sub_test_flow.dxf]
2020-07-12 Add test line for both flow and control layer
    Also keep backup (AutoCAD) files off these sacred lands
    [biodisplay_sub_test_flow_control.dwg, biodisplay_sub_test_flow_control.dxf]
2020-07-14 Add single subexperiment design with inlets closer
    [biodisplay_sub_inlets_closer.dwg, biodisplay_sub_inlets_closer.dxf]
2020-07-14 Add chambers control channel on top design iter
    Not completed.
    [biodisplay_sub_control_chambers_on_top.dwg, biodisplay_sub_control_chambers_on_top.dxf]
2020-07-16 Add vacuum lane iteration
    Two versions, one as a separate VACUUM layer, one in the FLOW layer
    [biodisplay_sub_vacuum_line.dwg, biodisplay_sub_vacuum_line.dxf, biodisplay_sub_vacuum_line_in_flow.dwg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]
2020-07-17 Add design iteration screenshots
    Former-commit-id: c4e9124027f84926b7e2e6482f5c0dc0827280e5
    [biodisplay.dwg, biodisplay_sub_test_flow.dwg]
2020-07-17 Add .dwg, .dxf to LFS
    Previous files still referenced by previous commits, references aren't
    cleaned.
    [biodisplay.dwg, biodisplay.dxf, biodisplay_sub.dwg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]
2020-07-20 Fix non-closed objects
    Lines are considered to be of infinitesmal thickness and only closed
    regions are recognized by the printer
    [biodisplay_sub.dwg, biodisplay_sub.dxf, biodisplay_sub_control_chambers_on_top.dwg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]
2020-08-15 Add incremented chamber distance design with flow test line
    [biodisplay_sub_inlets_closer_incr_dist.dwg, biodisplay_sub_inlets_closer_incr_dist.dxf, biodisplay_sub_inlets_closer_incr_dist_test_flow.dwg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]
2020-08-18 Add Inlets closer test flow design
    [biodisplay_sub_inlets_closer_incr_dist_test_flow.dwg, biodisplay_sub_inlets_closer_incr_dist_test_flow.dxf, inlets_closer_test_flow.dwg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]
2020-08-31 repair final sub test designs
    [biodisplay_sub_inlets_closer_incr_dist_test_flow.dwg, biodisplay_sub_inlets_closer_incr_dist_test_flow.dxf]
2020-08-31 add final design
    [final.dwg, final.dxf]
2020-08-31 repair final design
    [final.dwg, final.dxf]
2020-08-31 repair chambers in sub final design
    [biodisplay_sub_inlets_closer_incr_dist_test_flow.dwg, biodisplay_sub_inlets_closer_incr_dist_test_flow.dxf]
2020-09-01 repair final sub design without test channel files
    [biodisplay_sub_inlets_closer_incr_dist.dwg, biodisplay_sub_inlets_closer_incr_dist.dxf]
2020-09-14 Added flow_control_redundancy.drawio
2020-09-14 Preliminary work to flow_control_redundancy.drawio
2020-09-15 Updated flow_control_redundancy.drawio
2020-09-15 Updated (again) flow_control_redundancy.drawio
2020-09-16 Added final chip for 3 sub-experiments & test line
    [final.dwg, final.dxf]
2020-09-19 Fixed connected control lines in final
    [final.dwg]
2020-09-19 Added .dxf version
    [final.dxf]
2021-01-29 Fix Control inlets; Flow outlets
    Non-closed polylines, redundant lines, misplaced lines...
    [final.dxf, test_line.dxf]
2021-01-29 Increase distance between control inlets
    [final.dxf, test_line.dxf]
2021-01-29 Add LICENSE files
    CERN-OHL-P for the CAD files, CC-BY-4.0 for the image and .drawio files
2021-05-11 Changed valve model in legend
2021-05-14 Corrected valve model error
2022-11-25 design diy temp ctrl system v1.0
    [Enclosure setup assembly.stp]
2022-12-15 Remove enclosure assembly (moved to spotting repo)
    [Enclosure setup assembly.stp]
2023-05-26 Biodisplay yeast
    [Biodisplay_spacedot.dwg, Biodisplay_spacedot.dxf]
2023-05-26 MITOMI yeast
    [MITOMI_incr_dist_spacedot.dwg, MITOMI_incr_dist_spacedot.dxf, MITOMI_spacedot.dwg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]
2023-08-04 Add 3 sub-experiment MITOMI
    [MITOMI_spacedot_final.dwg]
2023-08-04 Update 3 sub-experiment MITOMI dimensions
    [MITOMI_spacedot_final.dwg]
2023-08-04 Modify 3 sub-experiment MITOMI dimensions
    [MITOMI_spacedot_final.dwg]
2024-02-08 Designs cleanup
    [Biodisplay_spacedot.dwg, Biodisplay_spacedot.dxf, Biodisplay_spacedot_CDR_complete.dxf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]
2024-03-16 Update complete baseline MITOMI
    [MITOMI_spacedot_complete.dwg]
2024-03-16 Fix layers & compatibility with Klayout
    [MITOMI_spacedot_complete.dwg, MITOMI_spacedot_complete.dxf]
2024-04-23 Add 20240414-contact angle
    [20240414_MITOMI_contact_angle.csv]
2024-10-20 31mm distance between transmitted light source and spots -upside priming. Not compatible with microscope
    [slide_holder__v1_-31mm_height.SLDPRT]
2024-10-20 Upload New File
    [slide_holder_13mm_height__+1mm__-invetred_priming.SLDPRT]
2024-10-20 final slide holder .STL
    [slide_holder_13mm_height__+1mm__-invetred_priming.STL]
2025-02-24 SMP3 microarraying pin cleaning rack for sonication [.SLDPRT]
    [pin_holder_sonicator.SLDPRT]
2025-02-24 SMP3 microarraying pin cleaning rack for sonication [STL]
    [pin_holder_sonicator.STL]
2025-03-30 holds 2 chip holder with slots
    [double_holder_slot__for_top_and_bottom_v4.SLDPRT]
